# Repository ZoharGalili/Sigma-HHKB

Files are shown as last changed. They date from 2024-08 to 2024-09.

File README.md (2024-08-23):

# **This Is a Skibidi Sigma HHKB Keyboard**

gummy o-ring mount

rotary encoder

S series unified daughterboard https://github.com/Unified-Daughterboard/UDB-S

original custom design hhkb only pcb (kicad 8)

custom case (solidworks 2023), inspiared by the bakeneko 60 https://github.com/kkatano/bakeneko-60

plate generated by ai03 plate generator and modified in cad https://kbplate.ai03.com/

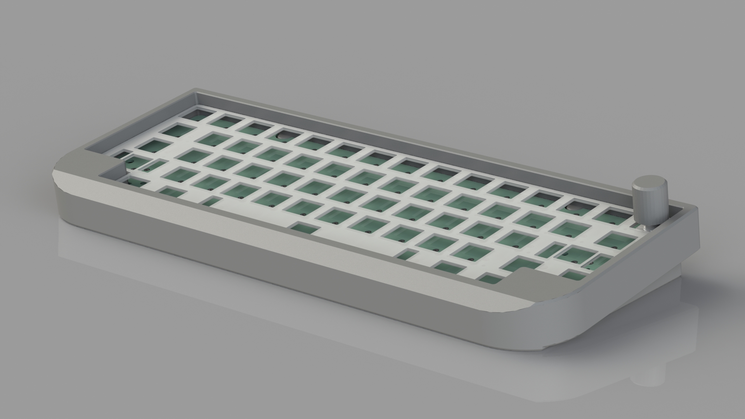
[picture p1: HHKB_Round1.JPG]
Case Render


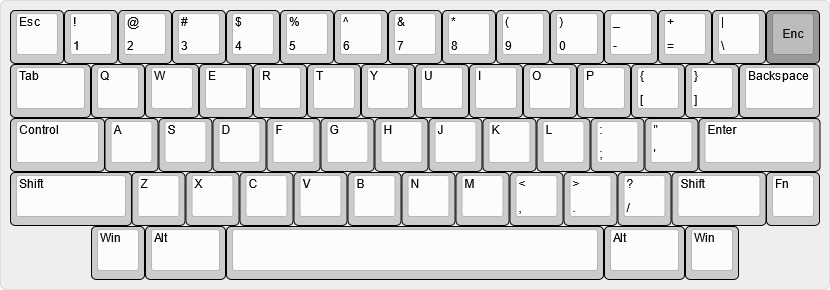
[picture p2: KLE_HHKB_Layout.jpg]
KLE Layout


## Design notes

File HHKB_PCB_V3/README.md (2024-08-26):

# **keyboard PCB**
## *we managed to get the pcb to fully work lets go*
but it didnt go without issues of course.
at first i didnt know how to get the stm32 into bootloader
and the first time i flashed it the code didnt compile due to syntax errors
and the json was wrong so the keys werent assained properly
and i suck at soldering so a few diodes and sockets were soldered only on one side
but at the end of the daay we had a fully working pcb so we got to work on the second one
on the second pcb we had a 3v3 and GND short that we couldnt find
our solution was to take to mcu and try to solder it to a new pcb and check for shorts each time we soldered a new component
the mcu was kida beat up from all the transfering and soldering so a few of its pins were kinda lifted up from the pcb
pushing them down and putting more solder paste did the trick and it worked

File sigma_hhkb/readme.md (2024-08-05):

# sigma_hhkb

sigma_hhkb

*A short description of the keyboard/project*

* Keyboard Maintainer: [ZoharGalili](https://github.com/ZoharGalili)
* Hardware Supported: *The PCBs, controllers supported*
* Hardware Availability: *Links to where you can find this hardware*

Make example for this keyboard (after setting up your build environment):

    make sigma_hhkb:default

Flashing example for this keyboard:

    make sigma_hhkb:default:flash

See the [build environment setup](https://docs.qmk.fm/#/getting_started_build_tools) and the [make instructions](https://docs.qmk.fm/#/getting_started_make_guide) for more information. Brand new to QMK? Start with our [Complete Newbs Guide](https://docs.qmk.fm/#/newbs).

## Bootloader

Enter the bootloader in 3 ways:

* **Bootmagic reset**: Hold down the key at (0,0) in the matrix (usually the top left key or Escape) and plug in the keyboard
* **Physical reset button**: Briefly press the button on the back of the PCB - some may have pads you must short instead
* **Keycode in layout**: Press the key mapped to `QK_BOOT` if it is available

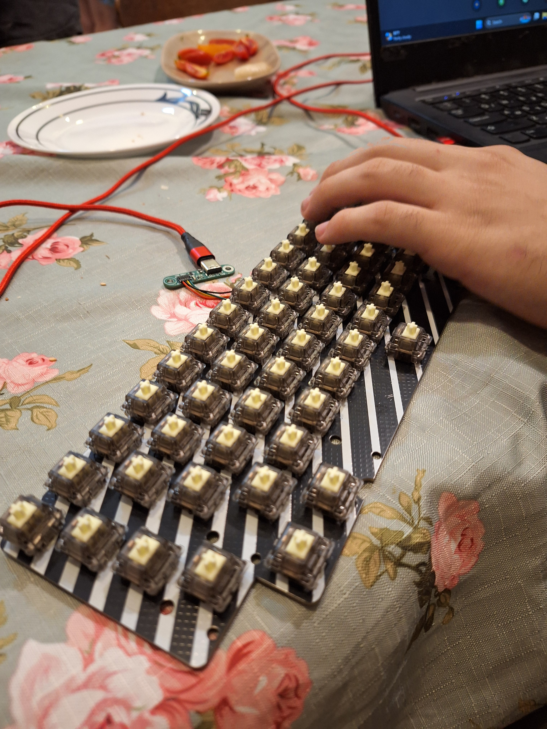
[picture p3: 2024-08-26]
HHKB_PCB_V3/20240825_212509[1].jpg

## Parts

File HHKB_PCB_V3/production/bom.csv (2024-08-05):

Designator | Footprint | Quantity | Value | LCSC Part #
C1, C3, C4, C5, C6, C7 | 0402 | 6 | 100nF | C1525
C10, C9 | 0402 | 2 | 1uF | C52923
C2 | 0603 | 1 | 10uF | C19702
D1, D10, D11, D12, D13, D14, D15, D16, D17, D18, D19, D2, D20, D21, D22, D23, D24, D25, D26, D27, D28, D29, D3, D30, D31, D32, D33, D34, D35, D36, D37, D38, D39, D4, D40, D41, D42, D43, D44, D45, D46, D47, D48, D49, D5, D50, D51, D52, D53, D54, D55, D56, D57, D58, D59, D6, D60, D7, D8, D9 | D_SOD-123 | 60 | D_Small | C81598
J1 | Molex_Pico-EZmate_78171-0004_1x04-1MP_P1.20mm_Vertical | 1 | Conn_01x04 | C588524
MX1, MX10, MX11, MX12, MX13, MX14, MX15, MX16, MX17, MX18, MX19, MX2, MX20, MX21, MX22, MX23, MX24, MX25, MX26, MX27, MX28, MX29, MX3, MX30, MX31, MX32, MX33, MX34, MX35, MX36, MX37, MX38, MX39, MX4, MX40, MX41, MX42, MX43, MX44, MX45, MX46, MX47, MX48, MX49, MX5, MX50, MX51, MX52, MX53, MX54, MX55, MX56, MX57, MX58, MX59, MX6, MX7, MX8, MX9 | SW_MX_HS_CPG151101S11_1u | 59 | MX_SW_solder | C5156480
R3, R4 | 0402 | 2 | 5.1k | C25905
SW1 | ROT_Alps_EC11E-Switch | 1 | RotaryEncoder_Switch | C470754
U1 | LQFP-48_7x7mm_P0.5mm | 1 | STM32F072CBT6 | C81720
U3 | SOT-23 | 1 | XC6206PxxxMR-Regulator_Linear | C5446

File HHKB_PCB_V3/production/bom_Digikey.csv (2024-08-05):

Designator | Footprint | Quantity | Value | Digikey Part #
C1, C3, C4, C5, C6, C7 | 0402 | 6 | 100nF | 1276-1001-1-ND
C10, C9 | 0402 | 2 | 1uF | 1276-1445-1-ND
C2 | 0603 | 1 | 10uF | 1276-1192-1-ND
D1, D10, D11, D12, D13, D14, D15, D16, D17, D18, D19, D2, D20, D21, D22, D23, D24, D25, D26, D27, D28, D29, D3, D30, D31, D32, D33, D34, D35, D36, D37, D38, D39, D4, D40, D41, D42, D43, D44, D45, D46, D47, D48, D49, D5, D50, D51, D52, D53, D54, D55, D56, D57, D58, D59, D6, D60, D7, D8, D9 | D_SOD-123 | 60 | D_Small | 641-1669-1-ND
J1 | Molex_Pico-EZmate_78171-0004_1x04-1MP_P1.20mm_Vertical | 1 | Conn_01x04 | WM4460CT-ND
R3, R4 | 0402 | 2 | 5.1k | P5.1KJCT-ND
SW1 | ROT_Alps_EC11E-Switch | 1 | RotaryEncoder_Switch | 4809-EC11E15244B2-ND
U1 | LQFP-48_7x7mm_P0.5mm | 1 | STM32F072CBT6 | 497-14645-ND
U3 | SOT-23 | 1 | XC6206PxxxMR-Regulator_Linear | 893-XC6206P332MR-GCT-ND

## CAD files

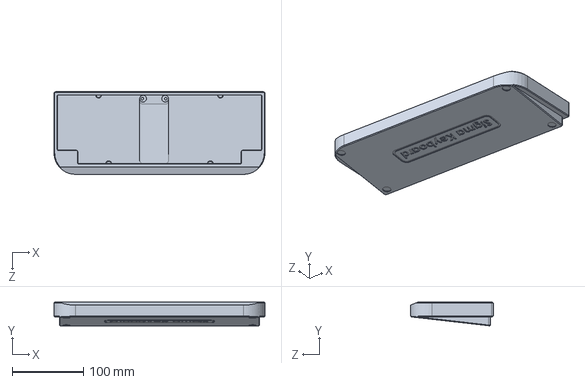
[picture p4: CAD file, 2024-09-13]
HHKB_Printed_Parts/HHKB_Case_Rounded.SLDPRT
296.8 x 33.4 x 116.2 mm

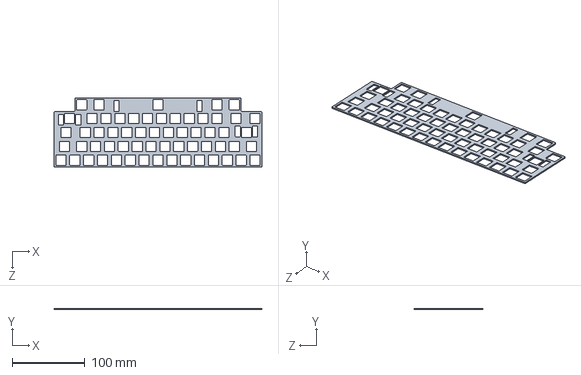
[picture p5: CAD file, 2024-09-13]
HHKB_Printed_Parts/HHKB_Plate_V2.SLDPRT
285.8 x 1.50 x 95.2 mm

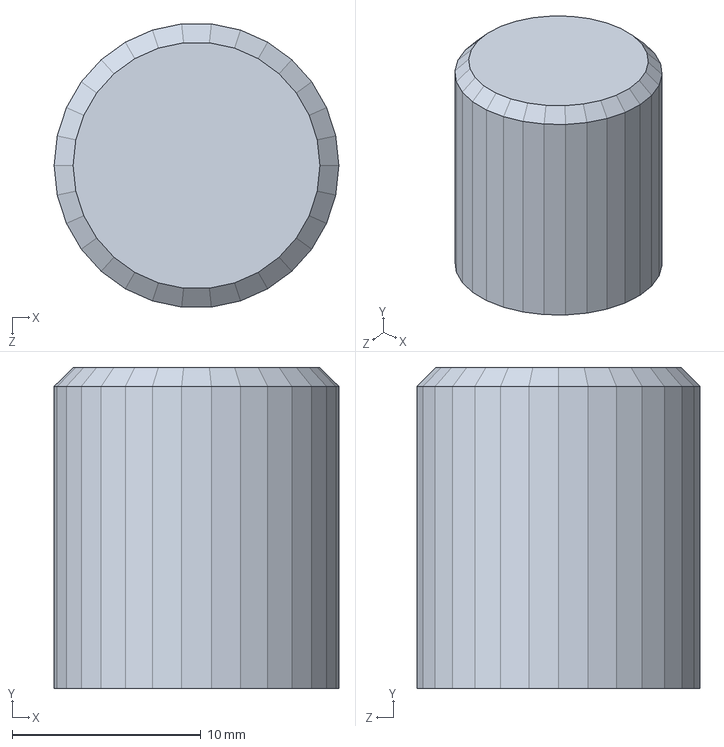
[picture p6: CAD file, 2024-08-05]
HHKB_Printed_Parts/Knob_V2.SLDPRT
15.1 x 17.0 x 15.0 mm

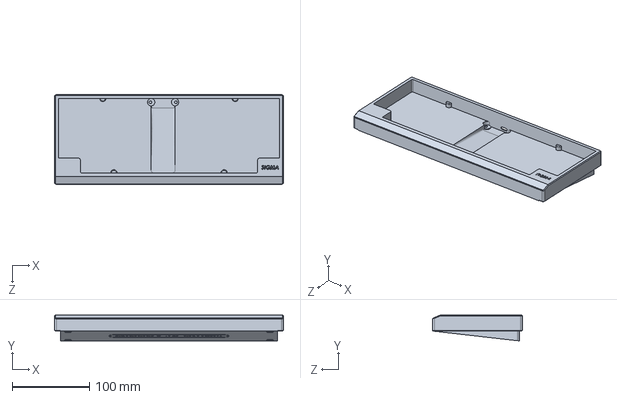
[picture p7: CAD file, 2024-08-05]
HHKB_Printed_Parts/HHKB_Case_V0.3.SLDPRT
296.8 x 33.5 x 116.2 mm

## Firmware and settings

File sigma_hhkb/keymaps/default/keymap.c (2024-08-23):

// Copyright 2023 QMK
// SPDX-License-Identifier: GPL-2.0-or-later

#include QMK_KEYBOARD_H

const uint16_t PROGMEM keymaps[][MATRIX_ROWS][MATRIX_COLS] = {
    /*
     * ┌───┬───┬───┬───┬───┬───┬───┬───┬───┬───┬───┬───┬───┬───┬───┐
     * │Esc│ 1 │ 2 │ 3 │ 4 │ 5 │ 6 │ 7 │ 8 │ 9 │ 0 │ - │ = │ \ │MUT│
     * ├───┴─┬─┴─┬─┴─┬─┴─┬─┴─┬─┴─┬─┴─┬─┴─┬─┴─┬─┴─┬─┴─┬─┴─┬─┴─┬─┴───┤
     * │ Tab │ Q │ W │ E │ R │ T │ Y │ U │ I │ O │ P │ [ │ ] │ Bspc│
     * ├─────┴┬──┴┬──┴┬──┴┬──┴┬──┴┬──┴┬──┴┬──┴┬──┴┬──┴┬──┴┬──┴─────┤
     * │ Ctrl │ A │ S │ D │ F │ G │ H │ J │ K │ L │ ; │ ' │  Enter │
     * ├──────┴─┬─┴─┬─┴─┬─┴─┬─┴─┬─┴─┬─┴─┬─┴─┬─┴─┬─┴─┬─┴─┬─┴────┬───┤
     * │ Shift  │ Z │ X │ C │ V │ B │ N │ M │ , │ . │ / │ Shift│MO1│
     * └─────┬──┴┬──┴──┬┴───┴───┴───┴───┴───┴───┴──┬┴───┴┬───┬─┴───┘
     *       │Alt│ GUI │                           │ GUI │Alt│
     *       └───┴─────┴───────────────────────────┴─────┴───┘
     */
    [0] = LAYOUT_60_hhkb(
        KC_ESC,  KC_1,    KC_2,    KC_3,    KC_4,    KC_5,    KC_6,    KC_7,    KC_8,    KC_9,    KC_0,    KC_MINS, KC_EQL,  KC_BSLS, KC_MUTE,
        KC_TAB,  KC_Q,    KC_W,    KC_E,    KC_R,    KC_T,    KC_Y,    KC_U,    KC_I,    KC_O,    KC_P,    KC_LBRC, KC_RBRC, KC_BSPC,
        KC_LCTL, KC_A,    KC_S,    KC_D,    KC_F,    KC_G,    K_H,    KC_J,    KC_K,    KC_L,    KC_SCLN,    KC_QUOT,       KC_ENT,
        KC_LSFT, KC_Z,    KC_X,    KC_C,    KC_V,    KC_B,    KC_N,    KC_M,    KC_COMM, KC_DOT,  KC_SLSH,     KC_RSFT,    MO(1),
                          KC_LALT, KC_LGUI,                   KC_SPC,                             KC_RGUI, KC_RALT
    ),

    /*
     * ┌───┬───┬───┬───┬───┬───┬───┬───┬───┬───┬───┬───┬───┬───┬───┐
     * │` ~│F1 │F2 │F3 │F4 │F5 │F6 │F7 │F8 │F9 │F10│F11│F12│Ins│PLY│
     * ├───┴─┬─┴───┴───┴───┴───┴───┴───┴─┬─┴─┬─┴─┬─┴─┬─┴─┬─┴───┴───┘
     * │Caps │ Q │ W │ E │ R │ T │ Y │ U │PSc│Scr│Pse│ ↑ │ ] │ Del │
     * └─────┘┌───┬───┬───┐──┴┬──┴┌───┬──┴┬──┴┬──┴┬──┴┬──┴┬────────┐
     * │ Ctrl │ A │ S │ D │ F │ G │ * │ / │Hom│PgU│ ← │ → │  Enter │
     * ├──────└───┴───┴───┘─┬─┴─┬─└─┬─┴─┬─┴─┬─┴─┬─┴─┬─┴─┬─┴────────┘
     * │ Shift  │ Z │ X │ C │ V │ B │ + │ - │End│PgD│ ↓ │ Shift│MO1│
     * └─────┬──┴┬──┴──┬┴───┴───┴───└───┴───┴───┴───┴───┘┬───┬─┴───┘
     *       │Alt│ GUI │                           │ GUI │Btl│
     *       └───┴─────┴───────────────────────────┴─────┴───┘
     */
    [1] = LAYOUT_60_hhkb(
        KC_GRV,  KC_F1,   KC_F2,   KC_F3,   KC_F4,   KC_F5,   KC_F6,   KC_F7,   KC_F8,   KC_F9,   KC_F10,  KC_F11,  KC_F12,  KC_INS, KC_MPLY,
        KC_CAPS, _______, _______, _______, _______, _______, _______, _______, KC_PSCR, KC_SCRL, KC_PAUS, KC_UP,   _______,  KC_DEL,
        _______, _______, _______, _______, _______, _______, KC_PAST, KC_PSLS, KC_HOME, KC_PGUP, KC_LEFT, KC_RGHT,          KC_PENT,
        _______, _______, _______, _______, _______, _______, KC_PPLS, KC_PMNS, KC_END,  KC_PGDN, KC_DOWN,      _______,     _______,
                          _______, _______,                   _______,                            _______, QK_BOOT
    )
};

#ifdef ENCODER_MAP_ENABLE
const uint16_t PROGMEM encoder_map[][NUM_ENCODERS][NUM_DIRECTIONS] = {
    [0] = { ENCODER_CCW_CW(KC_VOLU, KC_VOLD) },
    [1] = { ENCODER_CCW_CW(KC_MNXT, KC_MPRV) },
};
#endif

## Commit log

2024-08-05 parts for 3d printing
    [HHKB_Case_V0.3.SLDPRT, HHKB_Plate.SLDPRT, Knob_V2.SLDPRT]
2024-08-05 The pcb
    [HHKB.kicad_sch, Matrix.kicad_sch, bom.csv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]
2024-08-20 rounded case
    [HHKB_Case_Rounded.SLDPRT]
2024-08-23 Updated QMK Files
    i had some errors
    [keymap.c]
2024-09-13 V2 Plate
    [HHKB_Plate_V2.SLDPRT]
2024-09-13 fixed some stuff
    [HHKB_Case_Rounded.SLDPRT]
